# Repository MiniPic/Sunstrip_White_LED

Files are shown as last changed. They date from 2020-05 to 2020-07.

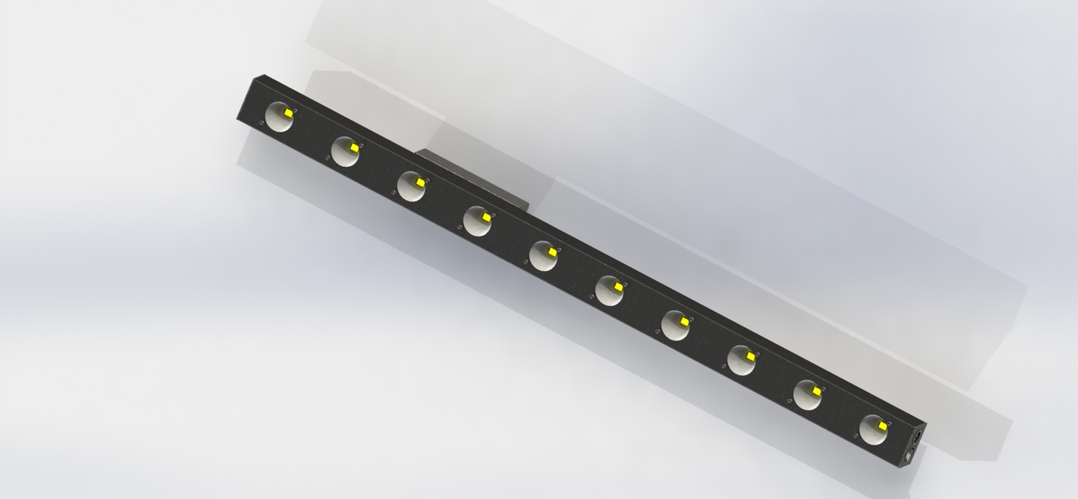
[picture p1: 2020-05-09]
Global.JPG

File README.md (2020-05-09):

# Sunstrip_White_LED
DIY Sunstrip 10x10W white LED
DMX control protocol

Deposite contain:
- mecanical design
- Software source
- PCB and Schematics

Sunstrip with : 
- 1 PCB for LED control
- 1 OLED display and 3 touch to configure DMX address
- 10 LED White 10W warm
- 2 XLR plugs
- extend by I2C
- 1 FAN output control

Software:
- Currently in progress

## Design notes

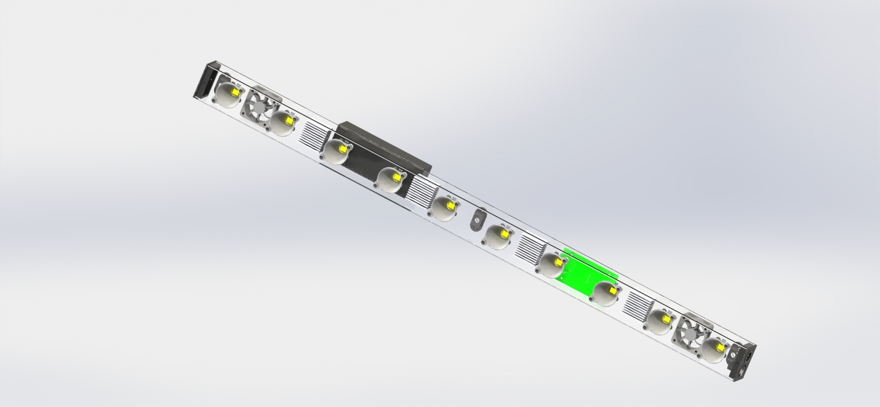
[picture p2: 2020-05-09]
Transparence.JPG

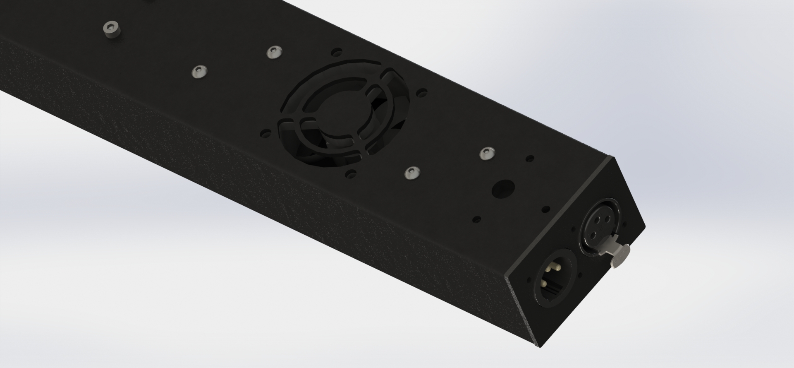
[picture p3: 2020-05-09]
Zoom.JPG

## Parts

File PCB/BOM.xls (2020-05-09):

Comment | Description | Designator | Footprint | LibRef | Quantity
100nF | Capacitor | C4, C9, C11, C12, C14, C18, C19, C20, C21, C22, C31, C32, C33 | C0603 | Cap | 13
10uF-50V | Capacitor | C10, C13, C17 | C1206 | Cap | 3
15pF | Capacitor | C15, C16 | C0603 | Cap | 2
T47V | TRANSIL CMS 47V unidirectionnelle | D5, D6, D7 | DIO47A | T47V | 3
3,6v | Zener Diode | D8, D9 | SOD123 | D Zener | 2
FUS 5X20 | FUSIBLE VERRE 5 x 20 | F1 | FUSPO-A1 | FUS 5X20 | 1
 | Programming Connector | J1 | CON_PROG | CON-PROG | 1
CUM/F3 | connecteur 3 points | J2 | HDR1X3 | CUM/F3 | 1
CUM/F4 | connecteur 4 points | J3, J4 | CNT4F5 | CUM/F4 | 2
CUM/F11 | connecteur 10 points | J5 | CNT11D | CUM/F11 | 1
CUM/F4 | connecteur 4 points | J6, J7 | CNT4S | CUM/F4 | 2
CUM/F2 | connecteur 2 points | J9 | CNT2H | CUM/F2 | 1
CUM/F8 | connecteur 8 points | J10 | BARF-2X4 | CUM/F8 | 1
LED-V | LED piquer ou CMS verte | L2 | LED-V1A | LED-V | 1
LOGO_NePasJeter | Logo Ne Pas Jeter (sérigraphie) | LOGO_1 | LogoNePasJeter | LOGO_NePasJeter | 1
LOGO_Poubelle | Logo poubelle (sérigraphie) | LOGO_2 | LogoPB | LOGO_Poubelle | 1
LOGO_CE | Logo CE (sérigraphie) | LOGO_3 | LogoCE | LOGO_CE | 1
 | I2C OLED 0.96" | M1 | I2C_OLED_0.96 | I2C-OLED-0.96 | 1
CTN5K | Photoresistance | P1 | DIV015 | CTN5K | 1
1k | Thin Metal Film Resistor | R1, R2, R3, R4, R5, R14, R18, R19, R20, R21, R22 | R0603 | Res | 11
10K | Thin Metal Film Resistor | R6, R10, R11, R12, R13, R17 | R0603 | Res | 6
100K | Thin Metal Film Resistor | R7, R8, R15, R42, R43, R44 | R0603 | Res | 6
1M | Thin Metal Film Resistor | R9 | R0603 | Res | 1
5K | Thin Metal Film Resistor | R16 | R0603 | Res | 1
TOUCHE | Touche | S4, S5, S6 | INT-CMS1 | TOUCHE | 3
VNS14NV04 | TRANSISTOR MOS N | T1, T2, T3, T4, T6, T7, T8, T9, T10, T11 | TRA14NV04 | VNS14NV04 | 10
BSR202N | TRANSISTOR MOS N | T5 | TRA202 | BSR202N | 1
STM32F103C8T6 | ARM Cortex-M3 32-bit MCU, 64 KB Flash, 20 KB Internal RAM, 37 I/Os, 48-pin LQFP, -40 to 85 degC, Tray | U2 | TQFP-48 | STM32F103C8T6 | 1
TLV1117 | LDO regulator 3.3V | U3 | SOT223 | TLV1117 | 1
78L05 | E:cms ;C1:faible conso; VD:TO220 debout; | U4 | REG5VE | 78L05 | 1
QUARTZ-8MHZ | QUARTZ 8 MHZ CMS | U5 | QUA8G | QUARTZ-8MHZ | 1
CI485 | DRIVER RS485 | U6 | CIA485A | CI485 | 1
V47V | VARISTANCE 47V BOITIER 1206 | V1, V2 | VAR47A | V47V | 2
VIS | VIS | VIS_1, VIS_2, VIS_3, VIS_4 | HOLE3.5mm | VIS | 4

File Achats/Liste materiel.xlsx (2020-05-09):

 |  |  | Total / Sunstrip | 39.43 €
Designation | qté/sunstrip | prix unitaire | Total | Commentaire | Lien internet
Barre aluminium | 1 | 8.64 € | 8.64 € |  | https://www.amazon.fr/gp/product/B07BR3SYKL/ref=ox_sc_act_title_1?smid=AX5VF8V55F4TS&th=1
LED 10W blanc chaud | 10 | 0.38 € | 3.80 € |  | https://fr.aliexpress.com/item/33029340248.html?scm_id=1007.13338.128125.0&scm-url=1007.13338.128125.0
Ventilateur | 2 | 0.80 € | 1.60 € |  | https://fr.aliexpress.com/item/4000212990708.html
Alimentation | 1 | 10.89 € | 10.89 € |  | https://fr.aliexpress.com/item/32870947978.html
PCB | 1 | 1.00 € | 1.00 € |  | https://www.seeedstudio.com/fusion_pcb.html
Composants |  |  | 0.00 €
Prise XLR Male | 1 | 1.39 € | 1.39 € |  | https://fr.aliexpress.com/item/32960932924.html?spm=a2g0o.cart.0.0.73b73c00JpMjK9&mp=1
Prise XLR Femelle | 1 | 1.39 € | 1.39 € |  | https://fr.aliexpress.com/item/32960932924.html?spm=a2g0o.cart.0.0.73b73c00JpMjK9&mp=1
Dissipateur | 4 | 1.85 € | 7.42 € |  | https://fr.aliexpress.com/item/32836367321.html
Vis M3x6 noir | 48 | 0.03 € | 1.44 € | 3 sachets nescessaires mini | https://fr.aliexpress.com/item/32822085395.html
pate thermique | 1 | 1.21 € | 1.21 € |  | https://fr.aliexpress.com/item/32955817773.html
Vis M4x20 | 22 | 0.03 € | 0.66 €

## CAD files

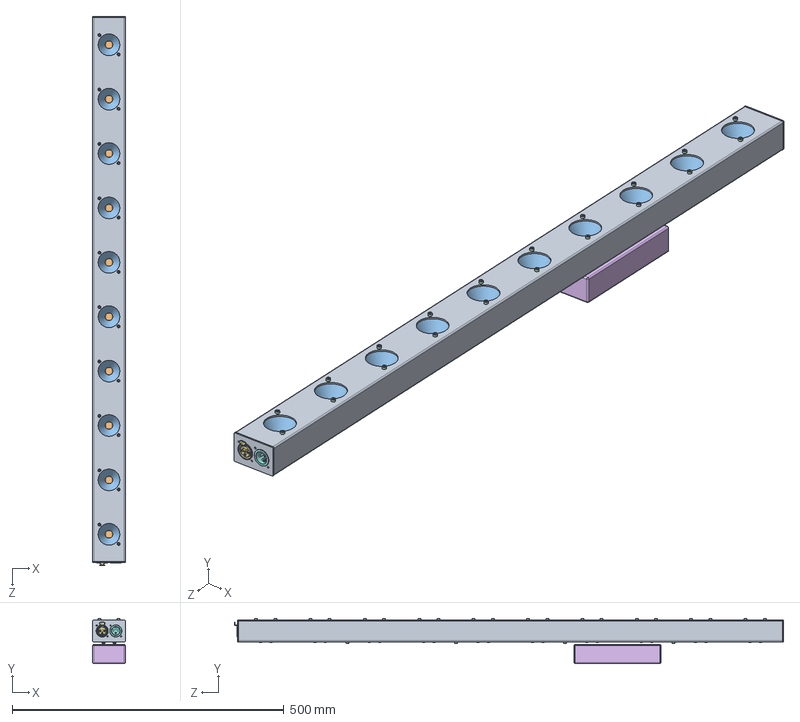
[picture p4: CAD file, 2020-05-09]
CAO/Assemblage.SLDASM
60.0 x 83.0 x 1009.4 mm
Alu 60x40
LED_10W x 10
Concentrateur x 10
socket head cap screw_iso x 28
Radiateur x 4
socket button head screw_iso x 20
plain washer 10669 type nl_iso x 20
hex thin nut gradeb_iso x 20
GDSTIME 50mm x 50mm x 20mm 12V Brushless Cooling Fan.stp x 2
PCB_Analyse
OLED 0.96'.step
Support_Ecrou_M8 x 3
Bouchon_bout
Alimentation 12V 120W
Neutrik NC3FAH2.stp
Neutrik NC3MAH-0.step
Bouchon_bout_prise

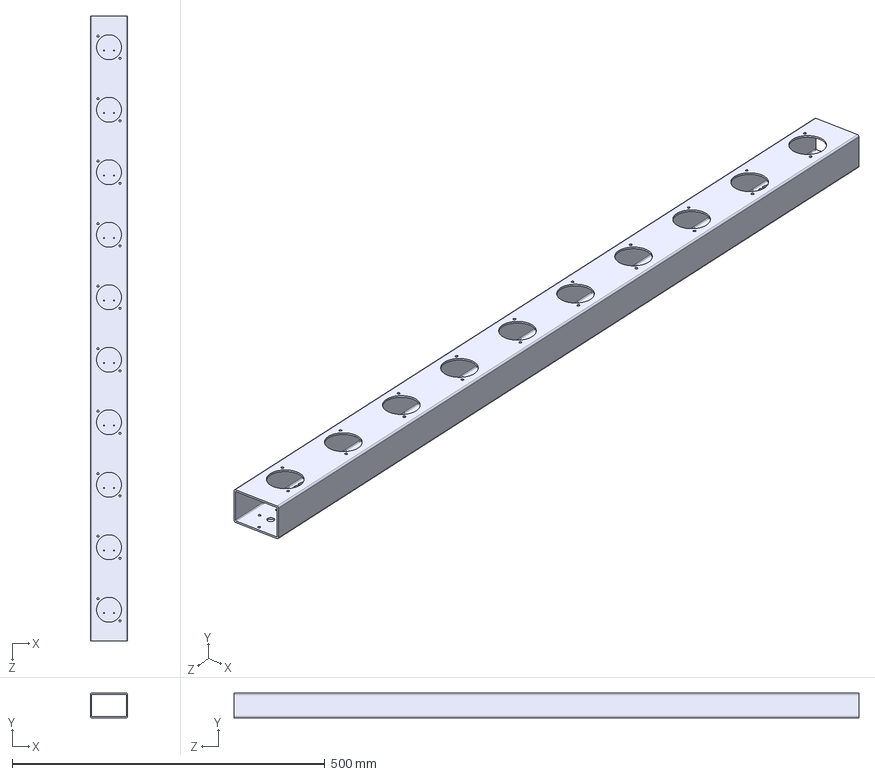
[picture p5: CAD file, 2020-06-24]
CAO/Alu 60x40.STEP
60.0 x 40.0 x 1000.0 mm

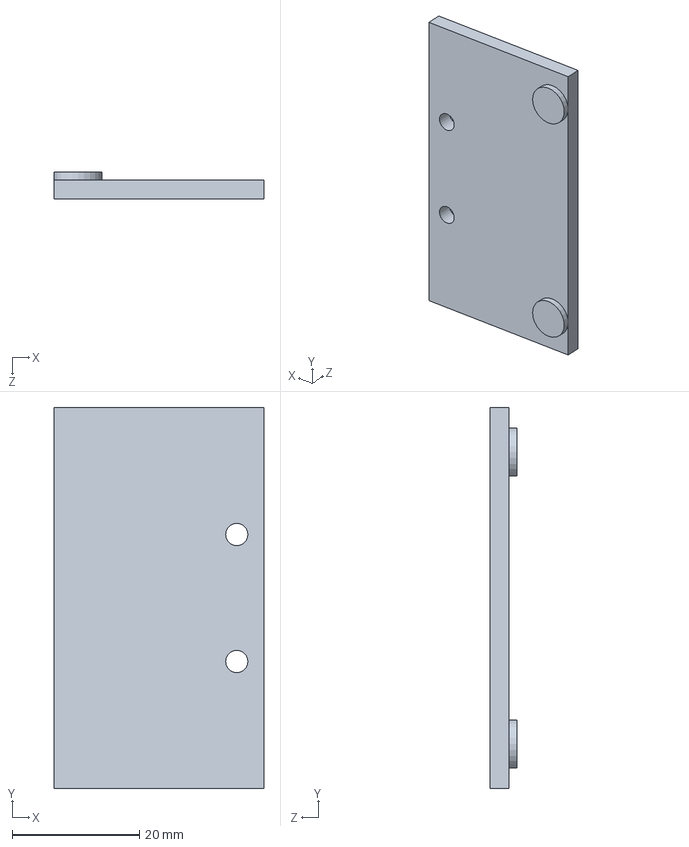
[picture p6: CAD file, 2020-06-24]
CAO/Bride_Alim.SLDPRT
33.0 x 60.0 x 4.20 mm

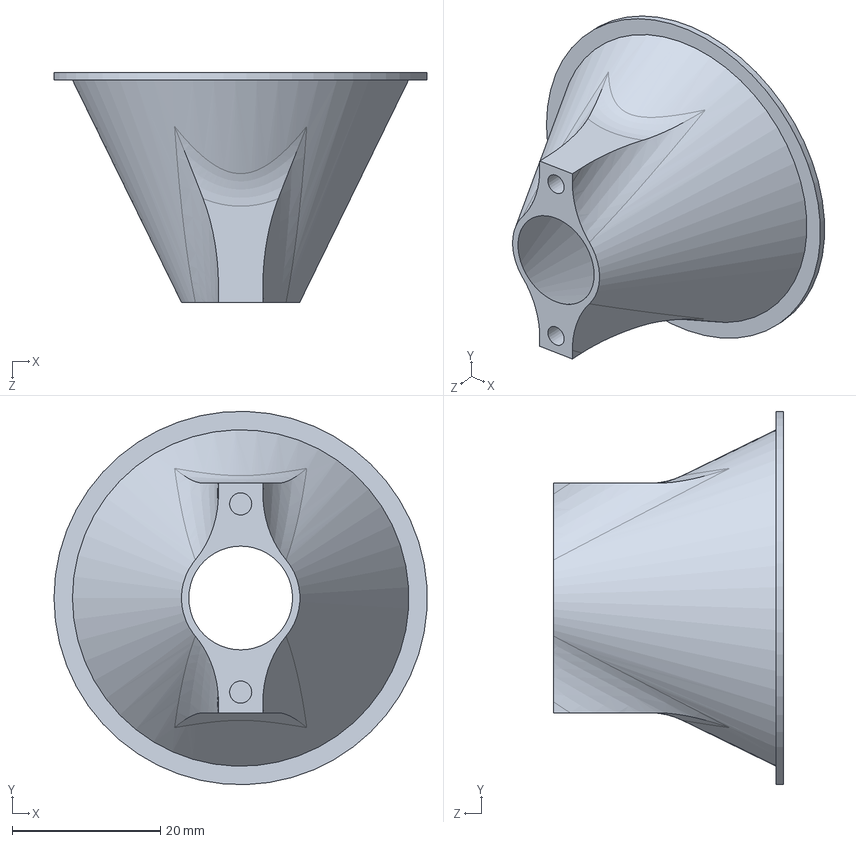
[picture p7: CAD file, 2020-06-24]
CAO/Concentrateur.SLDPRT
50.4 x 50.4 x 31.0 mm

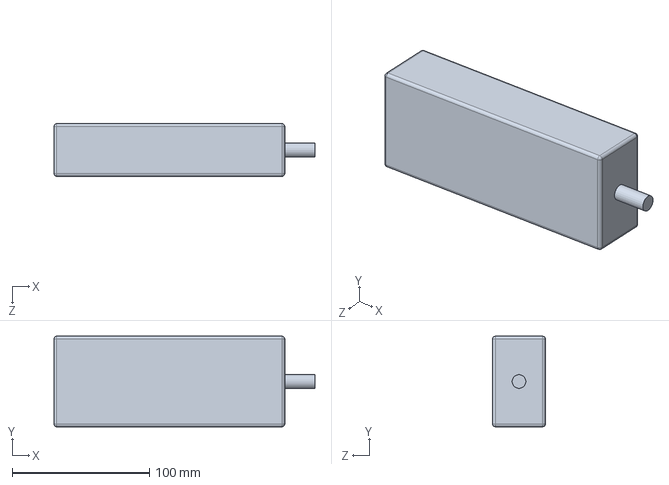
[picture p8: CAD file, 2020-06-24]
CAO/Alimentation 12V 120W.SLDPRT
190.0 x 66.0 x 38.4 mm

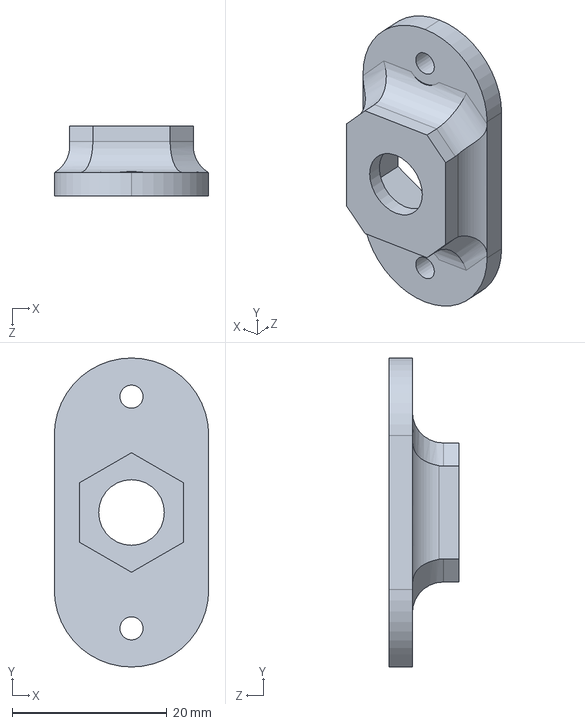
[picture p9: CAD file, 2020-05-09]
CAO/Support_Ecrou_M8.SLDPRT
20.0 x 40.0 x 9.00 mm

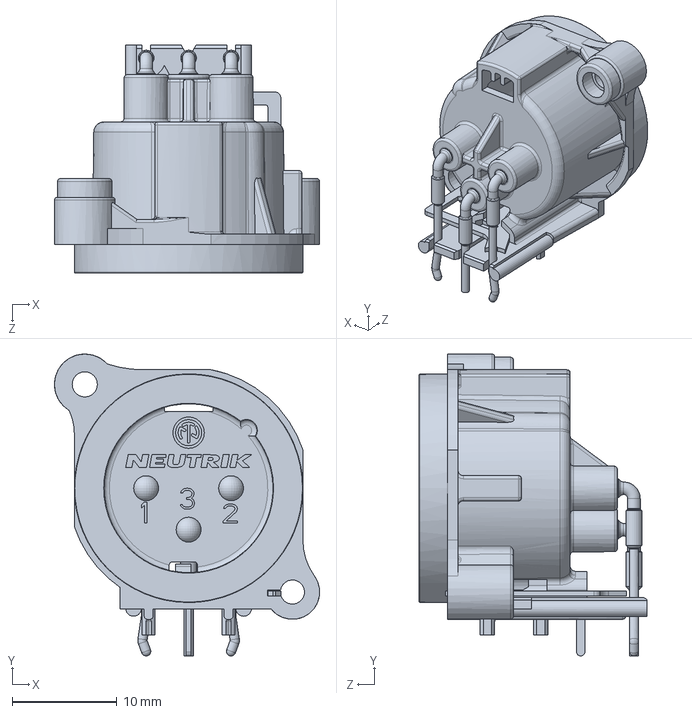
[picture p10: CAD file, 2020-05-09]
CAO/Neutrik NC3MAH-0.step.SLDPRT
25.3 x 28.8 x 21.7 mm

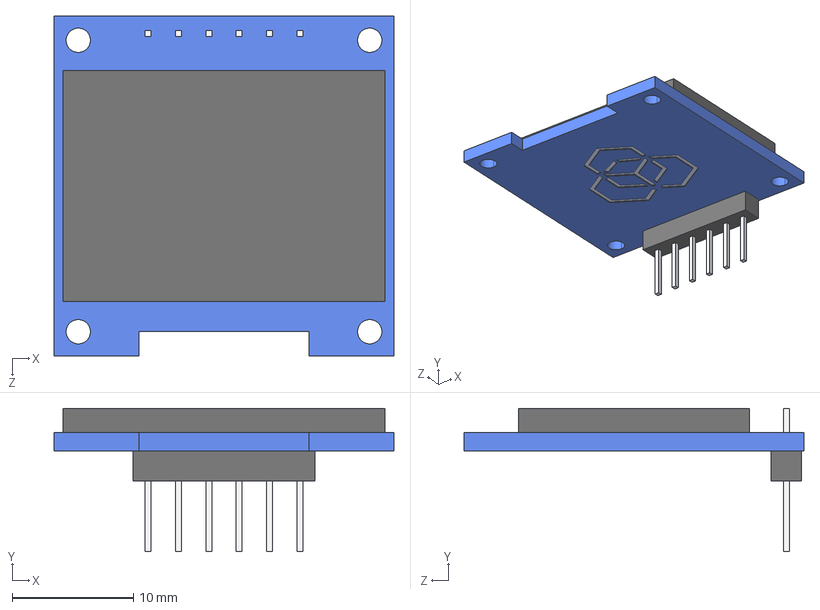
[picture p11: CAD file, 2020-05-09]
CAO/OLED 0.96'.STEP
28.0 x 11.8 x 28.0 mm

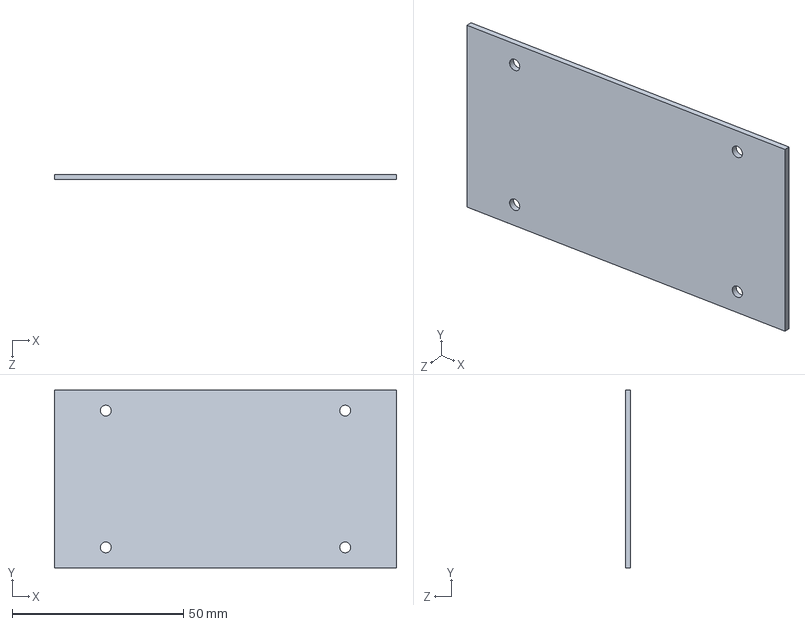
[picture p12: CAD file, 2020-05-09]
CAO/PCB_Analyse.SLDPRT
100.0 x 52.0 x 1.60 mm

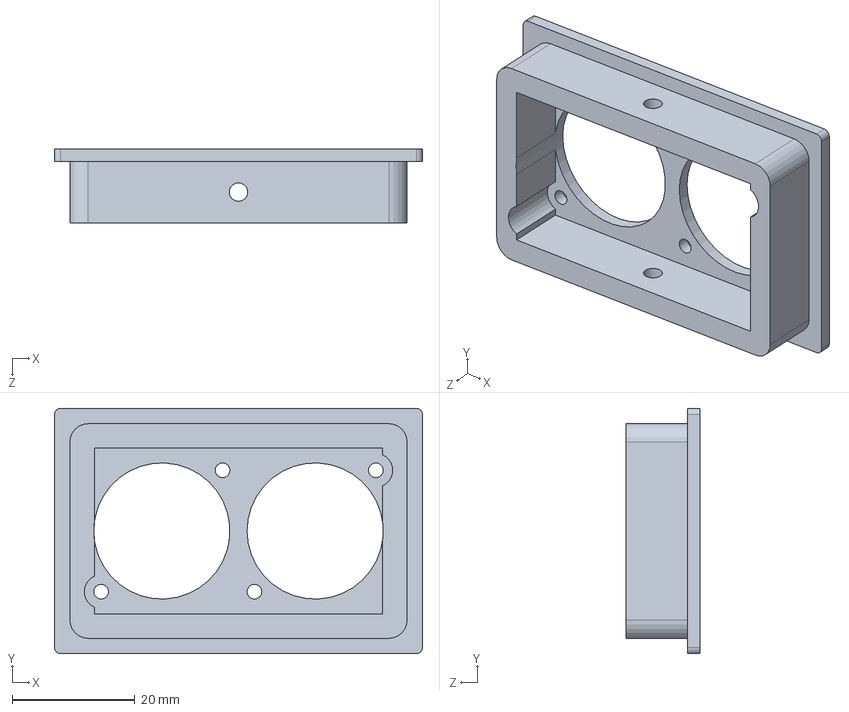
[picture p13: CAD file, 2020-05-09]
CAO/Bouchon_bout_prise.SLDPRT
60.0 x 40.0 x 12.0 mm

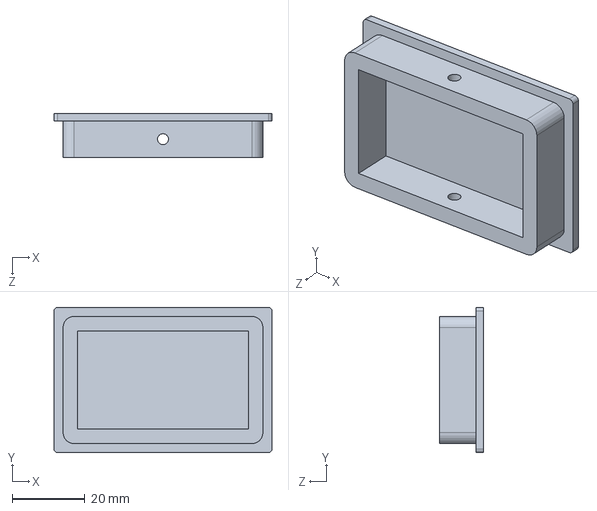
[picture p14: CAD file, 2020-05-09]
CAO/Bouchon_bout.SLDPRT
60.0 x 40.0 x 12.0 mm

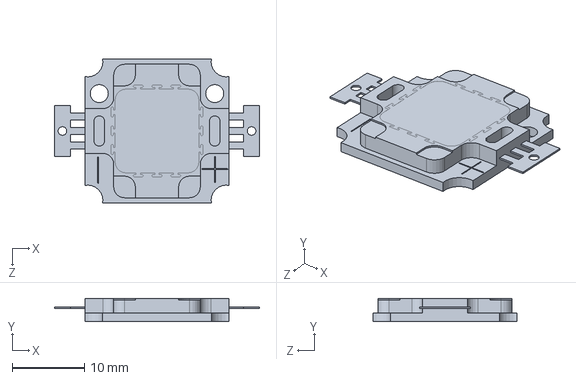
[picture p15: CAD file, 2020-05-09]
CAO/LED_10W.SLDPRT
28.4 x 3.20 x 20.0 mm

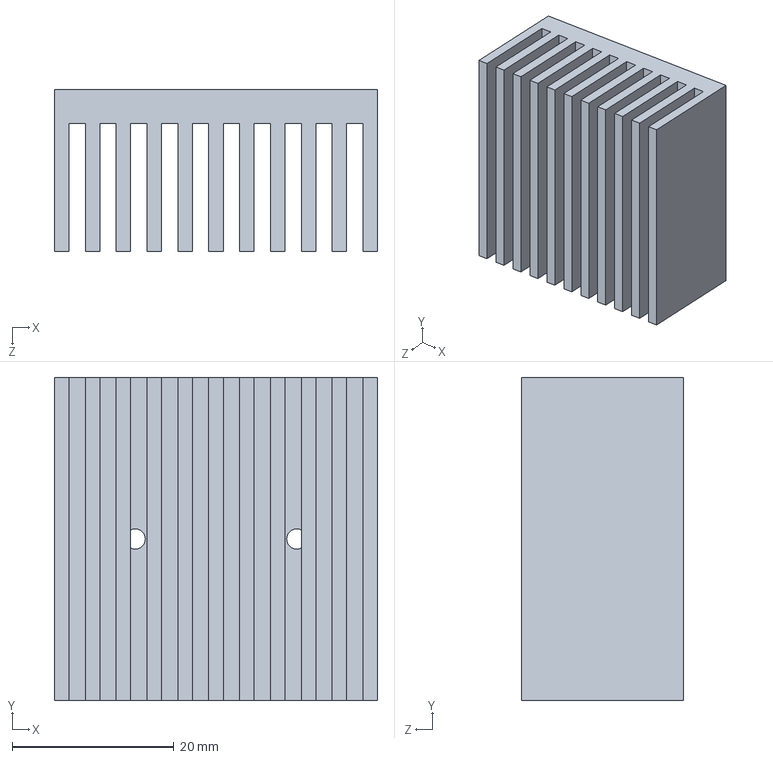
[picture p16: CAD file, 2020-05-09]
CAO/Radiateur.SLDPRT
40.0 x 40.0 x 20.0 mm

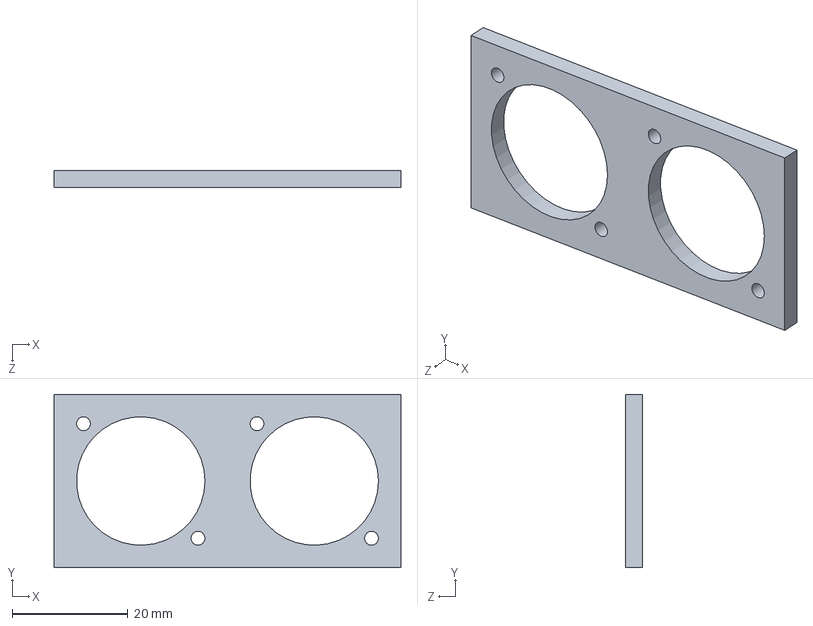
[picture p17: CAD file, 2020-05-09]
CAO/Support XLR.SLDPRT
60.0 x 30.0 x 3.00 mm

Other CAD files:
CAO/Neutrik NC3MAH-0.STEP
CAO/GDSTIME 50mm x 50mm x 20mm 12V Brushless Cooling Fan.stp
CAO/Neutrik NC3FAH2.stp.SLDPRT
CAO/socket head cap screw_iso.SLDPRT
CAO/Alu 60x40 - Copie.SLDPRT
CAO/Alu 60x40.SLDPRT
CAO/Concentrateur - Copie.SLDPRT
CAO/Concentrateur.STL
CAO/PCB_Analyse.DXF
CAO/Radiateur.SLDDRW

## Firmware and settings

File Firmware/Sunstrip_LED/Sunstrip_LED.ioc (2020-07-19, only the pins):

Mcu.UserName=STM32F103C8Tx
PA0-WKUP.GPIO_Label=PWM5
PA0-WKUP.Signal=S_TIM2_CH1_ETR
PA1.GPIO_Label=PWM6
PA1.Signal=S_TIM2_CH2
PA10.GPIO_Label=PWM2
PA10.Signal=S_TIM1_CH3
PA11.GPIO_Label=PWM1
PA11.Signal=S_TIM1_CH4
PA13.Signal=SYS_JTMS-SWDIO
PA14.Signal=SYS_JTCK-SWCLK
PA2.GPIO_Label=DMX_OUT
PA2.Signal=USART2_TX
PA3.GPIO_Label=DMX_IN
PA3.Signal=USART2_RX
PA7.GPIO_Label=CTN
PA7.Signal=ADCx_IN7
PA8.GPIO_Label=PWM4
PA8.Signal=S_TIM1_CH1
PA9.GPIO_Label=PWM3
PA9.Signal=S_TIM1_CH2
PB0.GPIO_Label=FAN
PB0.Signal=GPIO_Output
PB1.GPIO_Label=VOLTAGE
PB1.Signal=ADCx_IN9
PB10.GPIO_Label=PWM7
PB10.Signal=S_TIM2_CH3
PB11.GPIO_Label=PWM8
PB11.Signal=S_TIM2_CH4
PB12.GPIO_Label=T2
PB12.Signal=GPIO_Input
PB13.GPIO_Label=T3
PB13.Signal=GPIO_Input
PB4.GPIO_Label=PWM9
PB4.Signal=S_TIM3_CH1
PB5.GPIO_Label=PWM10
PB5.Signal=S_TIM3_CH2
PB6.GPIO_Label=USART_TX_DUBUG
PB6.Signal=USART1_TX
PB7.GPIO_Label=USART_RX_DUBUG
PB7.Signal=USART1_RX
PB8.GPIO_Label=SCL_IO
PB8.Signal=GPIO_Output
PB9.GPIO_Label=SDA_IO
PB9.Signal=GPIO_Output
PC13-TAMPER-RTC.GPIO_Label=LED_V
PC13-TAMPER-RTC.Signal=GPIO_Output
PC14-OSC32_IN.GPIO_Label=T1
PC14-OSC32_IN.Signal=GPIO_Input
PC15-OSC32_OUT.GPIO_Label=RE_DE
PC15-OSC32_OUT.Signal=GPIO_Output
PD0-OSC_IN.Signal=RCC_OSC_IN
PD1-OSC_OUT.Signal=RCC_OSC_OUT

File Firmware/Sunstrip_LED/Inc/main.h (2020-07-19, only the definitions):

#define LED_V_Pin GPIO_PIN_13
#define LED_V_GPIO_Port GPIOC
#define T1_Pin GPIO_PIN_14
#define T1_GPIO_Port GPIOC
#define RE_DE_Pin GPIO_PIN_15
#define RE_DE_GPIO_Port GPIOC
#define PWM5_Pin GPIO_PIN_0
#define PWM5_GPIO_Port GPIOA
#define PWM6_Pin GPIO_PIN_1
#define PWM6_GPIO_Port GPIOA
#define DMX_OUT_Pin GPIO_PIN_2
#define DMX_OUT_GPIO_Port GPIOA
#define DMX_IN_Pin GPIO_PIN_3
#define DMX_IN_GPIO_Port GPIOA
#define CTN_Pin GPIO_PIN_7
#define CTN_GPIO_Port GPIOA
#define FAN_Pin GPIO_PIN_0
#define FAN_GPIO_Port GPIOB
#define VOLTAGE_Pin GPIO_PIN_1
#define VOLTAGE_GPIO_Port GPIOB
#define PWM7_Pin GPIO_PIN_10
#define PWM7_GPIO_Port GPIOB
#define PWM8_Pin GPIO_PIN_11
#define PWM8_GPIO_Port GPIOB
#define T2_Pin GPIO_PIN_12
#define T2_GPIO_Port GPIOB
#define T3_Pin GPIO_PIN_13
#define T3_GPIO_Port GPIOB
#define PWM4_Pin GPIO_PIN_8
#define PWM4_GPIO_Port GPIOA
#define PWM3_Pin GPIO_PIN_9
#define PWM3_GPIO_Port GPIOA
#define PWM2_Pin GPIO_PIN_10
#define PWM2_GPIO_Port GPIOA
#define PWM1_Pin GPIO_PIN_11
#define PWM1_GPIO_Port GPIOA
#define PWM9_Pin GPIO_PIN_4
#define PWM9_GPIO_Port GPIOB
#define PWM10_Pin GPIO_PIN_5
#define PWM10_GPIO_Port GPIOB
#define USART_TX_DUBUG_Pin GPIO_PIN_6
#define USART_TX_DUBUG_GPIO_Port GPIOB
#define USART_RX_DUBUG_Pin GPIO_PIN_7
#define USART_RX_DUBUG_GPIO_Port GPIOB
#define SCL_IO_Pin GPIO_PIN_8
#define SCL_IO_GPIO_Port GPIOB
#define SDA_IO_Pin GPIO_PIN_9
#define SDA_IO_GPIO_Port GPIOB

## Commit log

2020-05-09 import PCB 3D from Altium
2020-06-24 update ioc file
    [Alimentation 12V 120W.SLDPRT, Alu 60x40 - Copie.SLDPRT, Alu 60x40.SLDPRT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]
2020-06-25 without i2c display for working PWM10
2020-07-12 i2c generated on i2c for fix bug inside MCU
    [Alu 60x40.SLDPRT]
2020-07-14 Chaser for debugg Channel 1 timer 1 not works
    [App.c, Sunstrip_LED.ioc]
2020-11-14 solve MANU No update PWM

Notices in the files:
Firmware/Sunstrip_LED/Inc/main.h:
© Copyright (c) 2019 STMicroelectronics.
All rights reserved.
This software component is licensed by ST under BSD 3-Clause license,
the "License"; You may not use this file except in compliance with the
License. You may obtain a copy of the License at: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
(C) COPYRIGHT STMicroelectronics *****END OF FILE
